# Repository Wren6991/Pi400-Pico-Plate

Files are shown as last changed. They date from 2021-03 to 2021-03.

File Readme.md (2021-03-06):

Pi 400 Pico Plate
=================

This board connects a Pico to the GPIO header on a Pi 400, without any wires flapping in the breeze. [See the schematic here (PDF)](pi400-pico-plate.pdf).

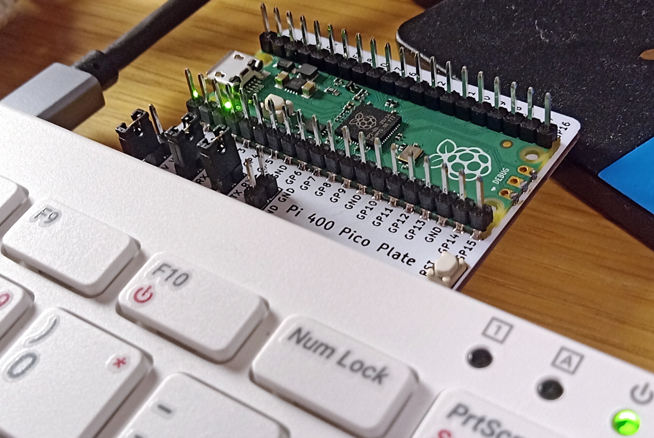
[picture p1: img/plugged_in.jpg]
A pi 400 with this board plugged into its GPIO socket. A small, white, squarish board, with a pico soldered on top of it, sticking out of the pi 400. A green light is illuminated on both the pico and the pi 400.


I made this to use at work. Besides connecting power and debug, it clearly labels the Pico pinout when viewed from the top:

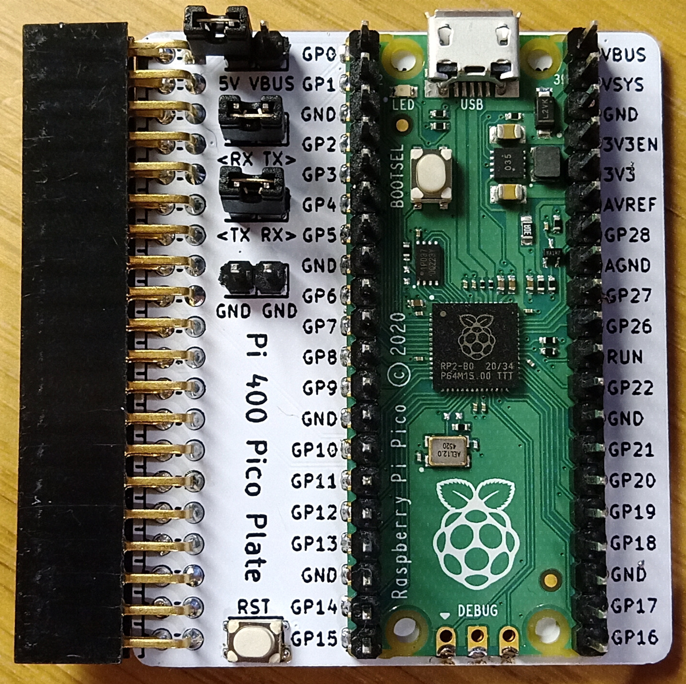
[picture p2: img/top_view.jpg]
Besides the pinout labels, you can also see the labels on the three jumpers. One connects pi 5v to vbus, another connects Pi UART RX to Pico TX, and the third connects Pi TX to Pico RX


- Pico VSYS is powered from Pi +5V rail
- Pico SWD is connected to Pi GPIO 24/25
- Pico RUN pin is connected to a push-button
- *(jumper)* Pico UART on GPIO0/1 is connected to Pi GPIO14/15
- *(jumper)* Pico VBUS is powered from +5V rail so Pico can function as USB host

That's it, that's the whole thing. This repository is CC0-licensed, with the exception of the 3d models in the `3d/` directory.

The board is designed with KiCad nightly; if you don't have KiCad nightly installed, you can find pregenerated gerbers of the rev A PCB in the `gerb/` directory, which are suitable for manufacture by JLCPCB.

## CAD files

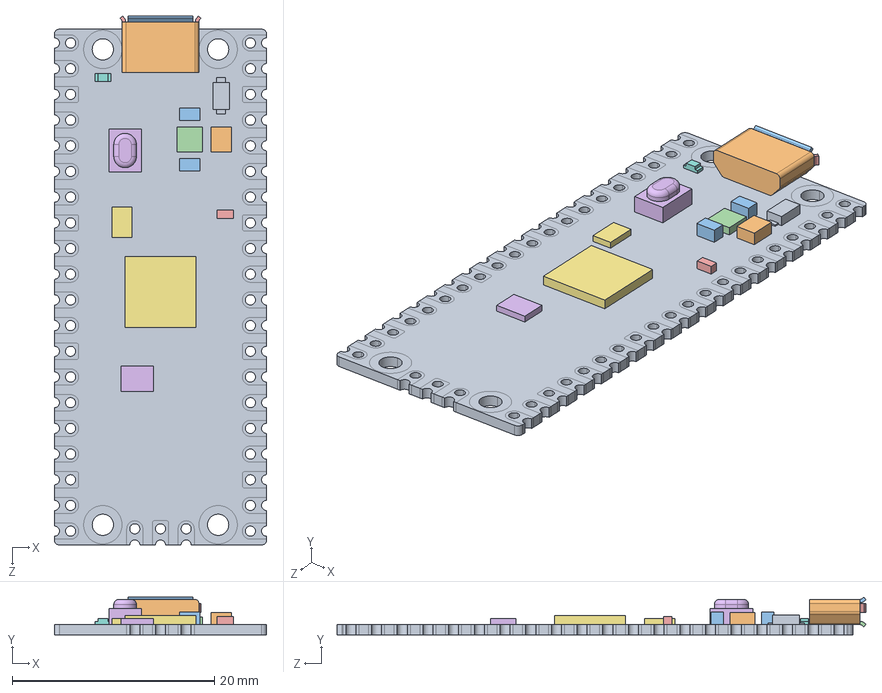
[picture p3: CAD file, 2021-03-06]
3d/Pico-R3.step
21.0 x 3.73 x 52.3 mm
PICO_REF_BOARD.STEP
PICO_REF_USB.STEP
PICO_REF_SWITCH.STEP
PICO_REF_MICROCONTROLLER.STEP
PICO_REF_LED.STEP
PICO_REF_ONSEMI.STEP
PICO_BOURNS.STEP
PICO_MURATA.STEP x 2
PICO_RICHTEK.STEP
PICO_DIODES.STEP
PICO_AEL.STEP
PICO_WINBOND.STEP

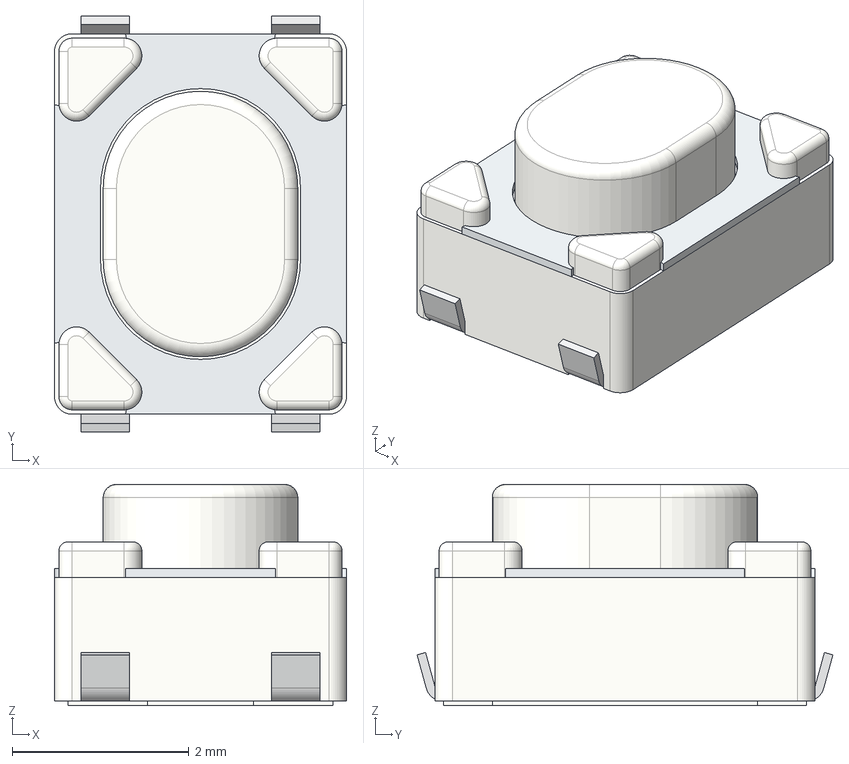
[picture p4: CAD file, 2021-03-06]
3d/PTS815SJK250.stp
3.30 x 4.70 x 2.50 mm

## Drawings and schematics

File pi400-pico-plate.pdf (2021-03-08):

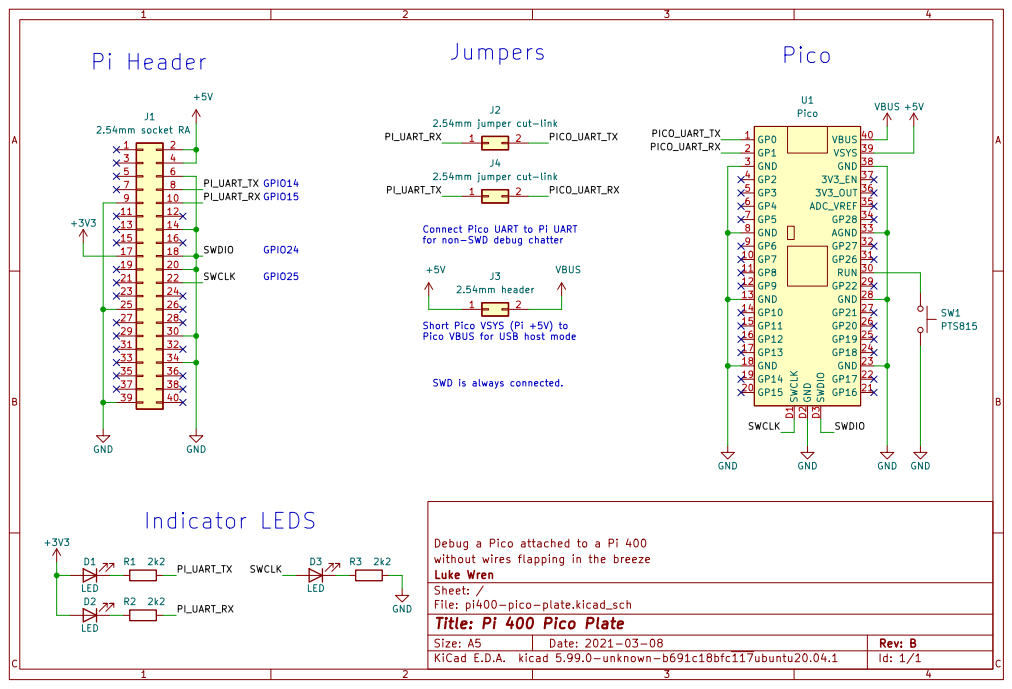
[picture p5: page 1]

for non-SWD debug chatter

SWD is always connected.

File: pi400-pico-plate.kicad_sch Sheet: / Luke Wren without wires flapping in the breeze

Id: 1/1 Title: Pi 400 Pico Plate

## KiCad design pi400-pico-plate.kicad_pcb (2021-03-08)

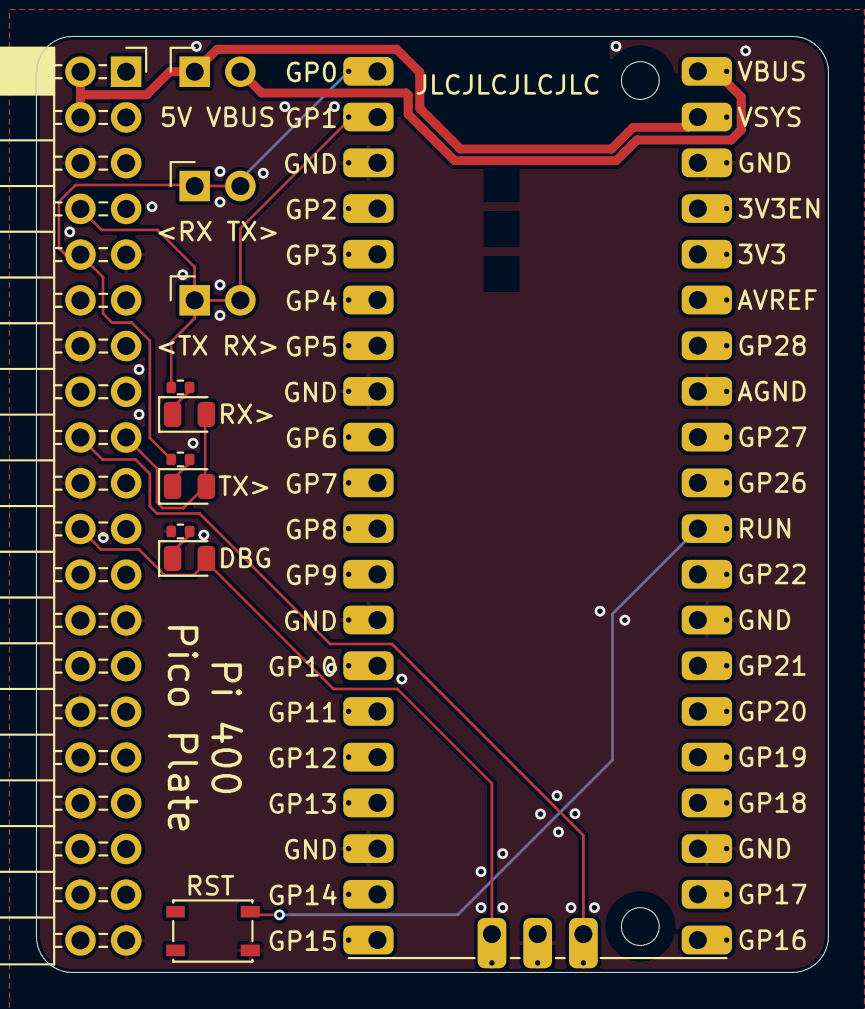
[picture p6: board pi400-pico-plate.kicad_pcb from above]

Board: 2 copper layers, 44.0 x 52.0 mm, 12 parts (0 on the bottom side), 14 nets.

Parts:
D1, D2, D3: LED; LED_0805_2012Metric
J1: 2.54mm socket RA; PinSocket_2x20_P2.54mm_Horizontal
J2, J4: 2.54mm jumper cut-link; 2.54mm- jumper-closed
J3: 2.54mm header; PinHeader_2x01_P2.54mm_Vertical
R1, R2, R3: 2k2; R_0402_1005Metric
SW1: PTS815; SW_SPST_PTS815
U1: Pico

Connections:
+3V3: D1.2 (A), D2.2 (A), J1.17
+5V: J1.2, J1.4, J3.1, U1.39 (VSYS)
/PICO_UART_RX: J4.2, U1.2 (GP1)
/PICO_UART_TX: J2.2, U1.1 (GP0)
/PI_UART_RX: J1.10, J2.1, R2.2
/PI_UART_TX: J1.8, J4.1, R1.2
/SWCLK: D3.2 (A), J1.22, U1.D1 (SWCLK)
/SWDIO: J1.18, U1.D3 (SWDIO)
GND: J1.6, J1.9, J1.14, J1.20, J1.25, J1.30, J1.34, J1.39, R3.2, SW1.2, U1.3 (GND), U1.8 (GND), U1.13 (GND), U1.18 (GND), U1.23 (GND), U1.28 (GND), U1.33 (AGND), U1.38 (GND), U1.D2 (GND)
unnamed: D1.1 (K), R1.1
unnamed: D2.1 (K), R2.1
unnamed: D3.1 (K), R3.1
unnamed: SW1.1, U1.30 (RUN)
VBUS: J3.2, U1.40 (VBUS)

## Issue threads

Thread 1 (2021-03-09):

Gerbers and Kicad files

peabody1929, 2021-03-09:
The Pi400-Pico_Plate is a GREAT design!  I have a Pi400 and I really want to use it with a Pico board.  I am trying to get a board Fab'd at JLCPCB.  Unfortunately, I have not been successful.

The Gerber files will not upload to JLCPCB to create a PCB.  The Gerber view option does not show the board.  I do not want to commit to a board fab if I can't see it at JLCPCB.

The Kicad files from this Github will not open.  I am using Kicad Version (5.1.9)-1 running on Windows 10.  I believe this is the current version.  I compared the ".PRO" file from this Github and a ".PRO" file on my PC that does open correctly, using a text editor.  The Github file uses ':' to define parameters.  My file uses '=' instead.  Is your version of Kicad current?  Is there a way to translate files to the current version of Kicad?

I look forward to resolving this issue and Fab'ing a board.

Best regards,
Tom

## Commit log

2021-03-06 Initial commit (rev A)
    [PTS815SJK250.stp, Pico-R3.step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]
2021-03-08 Start rev B changes -- make UART jumpers cut-link, remove aux GND header
    [pi400-pico-plate.kicad_pcb, pi400-pico-plate.kicad_sch]
2021-03-08 Add indicator LEDs, trim bottom board edge by 0.5 mm (by Pico SWD pads)
    [pi400-pico-plate.kicad_pcb, pi400-pico-plate.kicad_sch]
2021-03-08 Add mounting holes for standoffs. Power layout changed as a result
    [pi400-pico-plate.kicad_pcb, pi400-pico-plate.kicad_sch]
